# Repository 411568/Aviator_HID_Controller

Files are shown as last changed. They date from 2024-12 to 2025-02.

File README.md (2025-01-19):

<p align="center">Aviator_HID_Controller</p>

<h2>🧐 Features</h2>

The goal of this project was to design a HID controller for interfacing a number of buttons and encoders with the X-Plane flight simulator software.

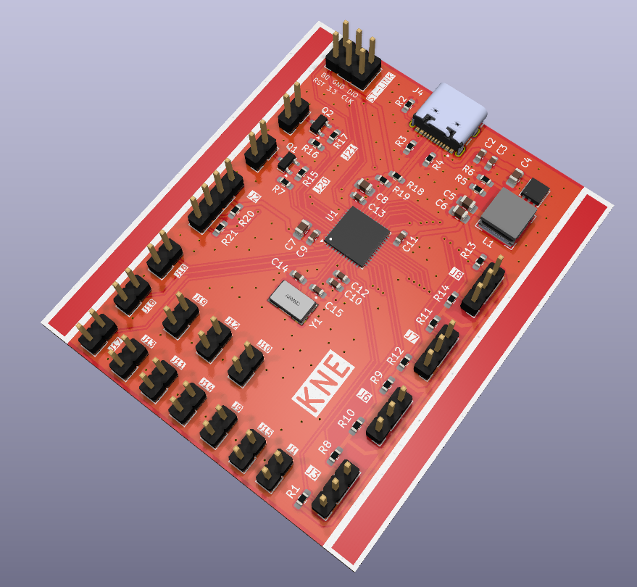
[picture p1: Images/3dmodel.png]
PCB 3d model


Here're some of the project's best features:

*  11 x button input
*  4 x rotary encoder input
*  1 x I2C interface connector
*  2 x 5V power output
*  USB type C for communication and power
*  HID keyboard interface

<h2>💻 Built with</h2>

Technologies used in the project:

*  STM32F072 microcontroller
*  ST1S06 buck converter
*  USB type C - HID communication
*  2-layer 0.8 mm FR4 PCB

<h2>🛡️ License:</h2>

This project is licensed under the MIT License.

<h2> 🙋‍♂️Authors </h2>

- Krzysztof Sikora

<h2>💖Like my work?</h2>

If you have any questions about the project feel free to contact us via email: krzysieksikora717@gmail.com

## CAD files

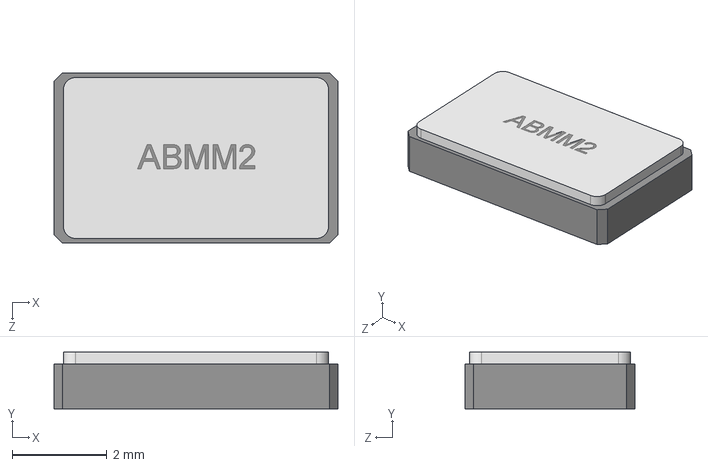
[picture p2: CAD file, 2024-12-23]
Aviator_Controller/components/ABMM2-32.000MHZ-E2F-T--3DModel-STEP-400430.STEP
6.00 x 1.20 x 3.60 mm

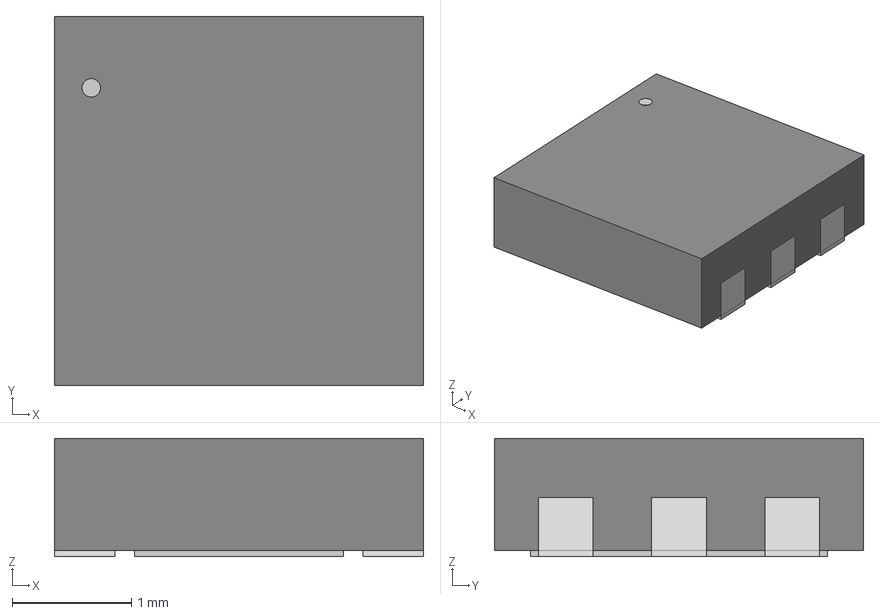
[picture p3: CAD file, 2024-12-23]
Aviator_Controller/components/ST1S06PU33R/DFN_6PU33R_STM.step
3.10 x 3.10 x 0.993 mm

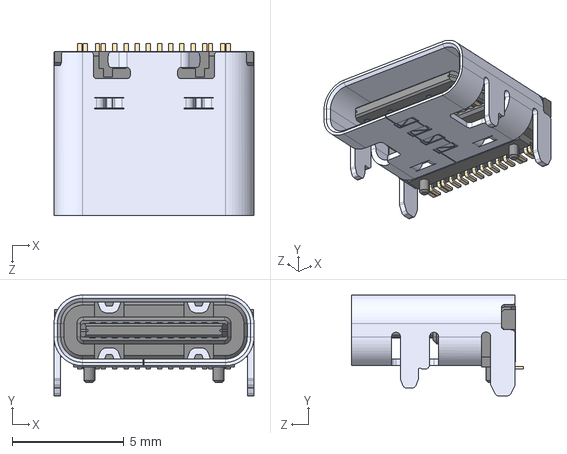
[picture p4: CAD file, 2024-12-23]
Aviator_Controller/components/USB4105GFA120/USB4105GFA120.step
8.94 x 4.51 x 7.71 mm

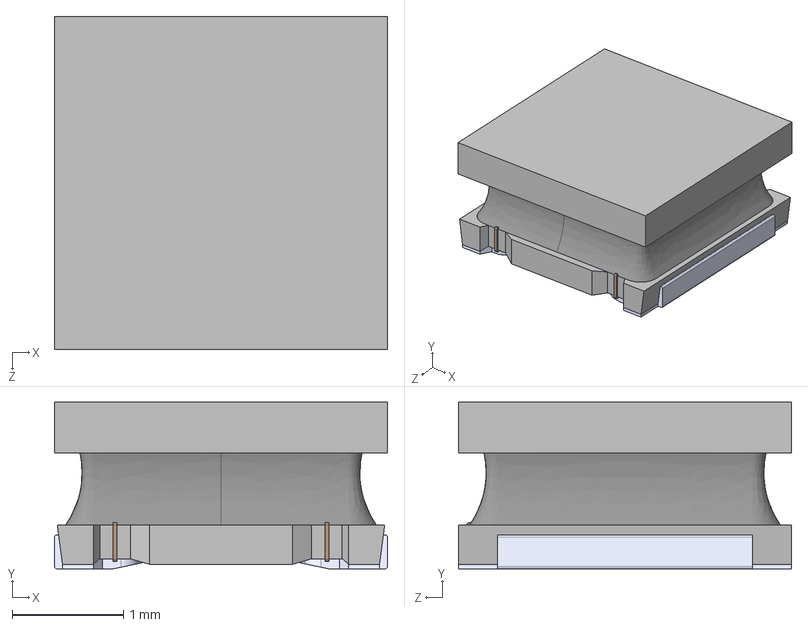
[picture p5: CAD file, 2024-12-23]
Aviator_Controller/components/LQH3NPN100MMEK.STEP
3.00 x 1.50 x 3.00 mm

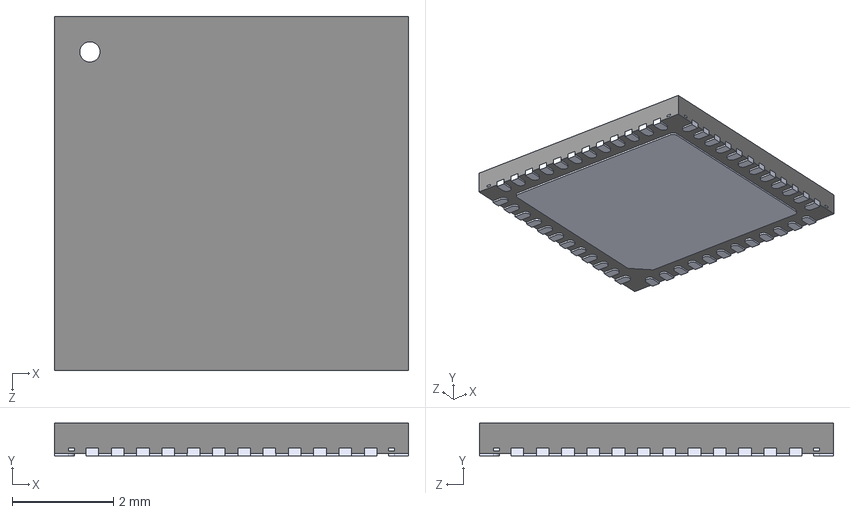
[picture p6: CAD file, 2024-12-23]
Aviator_Controller/components/STM32F072C8U6.STEP
7.00 x 0.65 x 7.00 mm

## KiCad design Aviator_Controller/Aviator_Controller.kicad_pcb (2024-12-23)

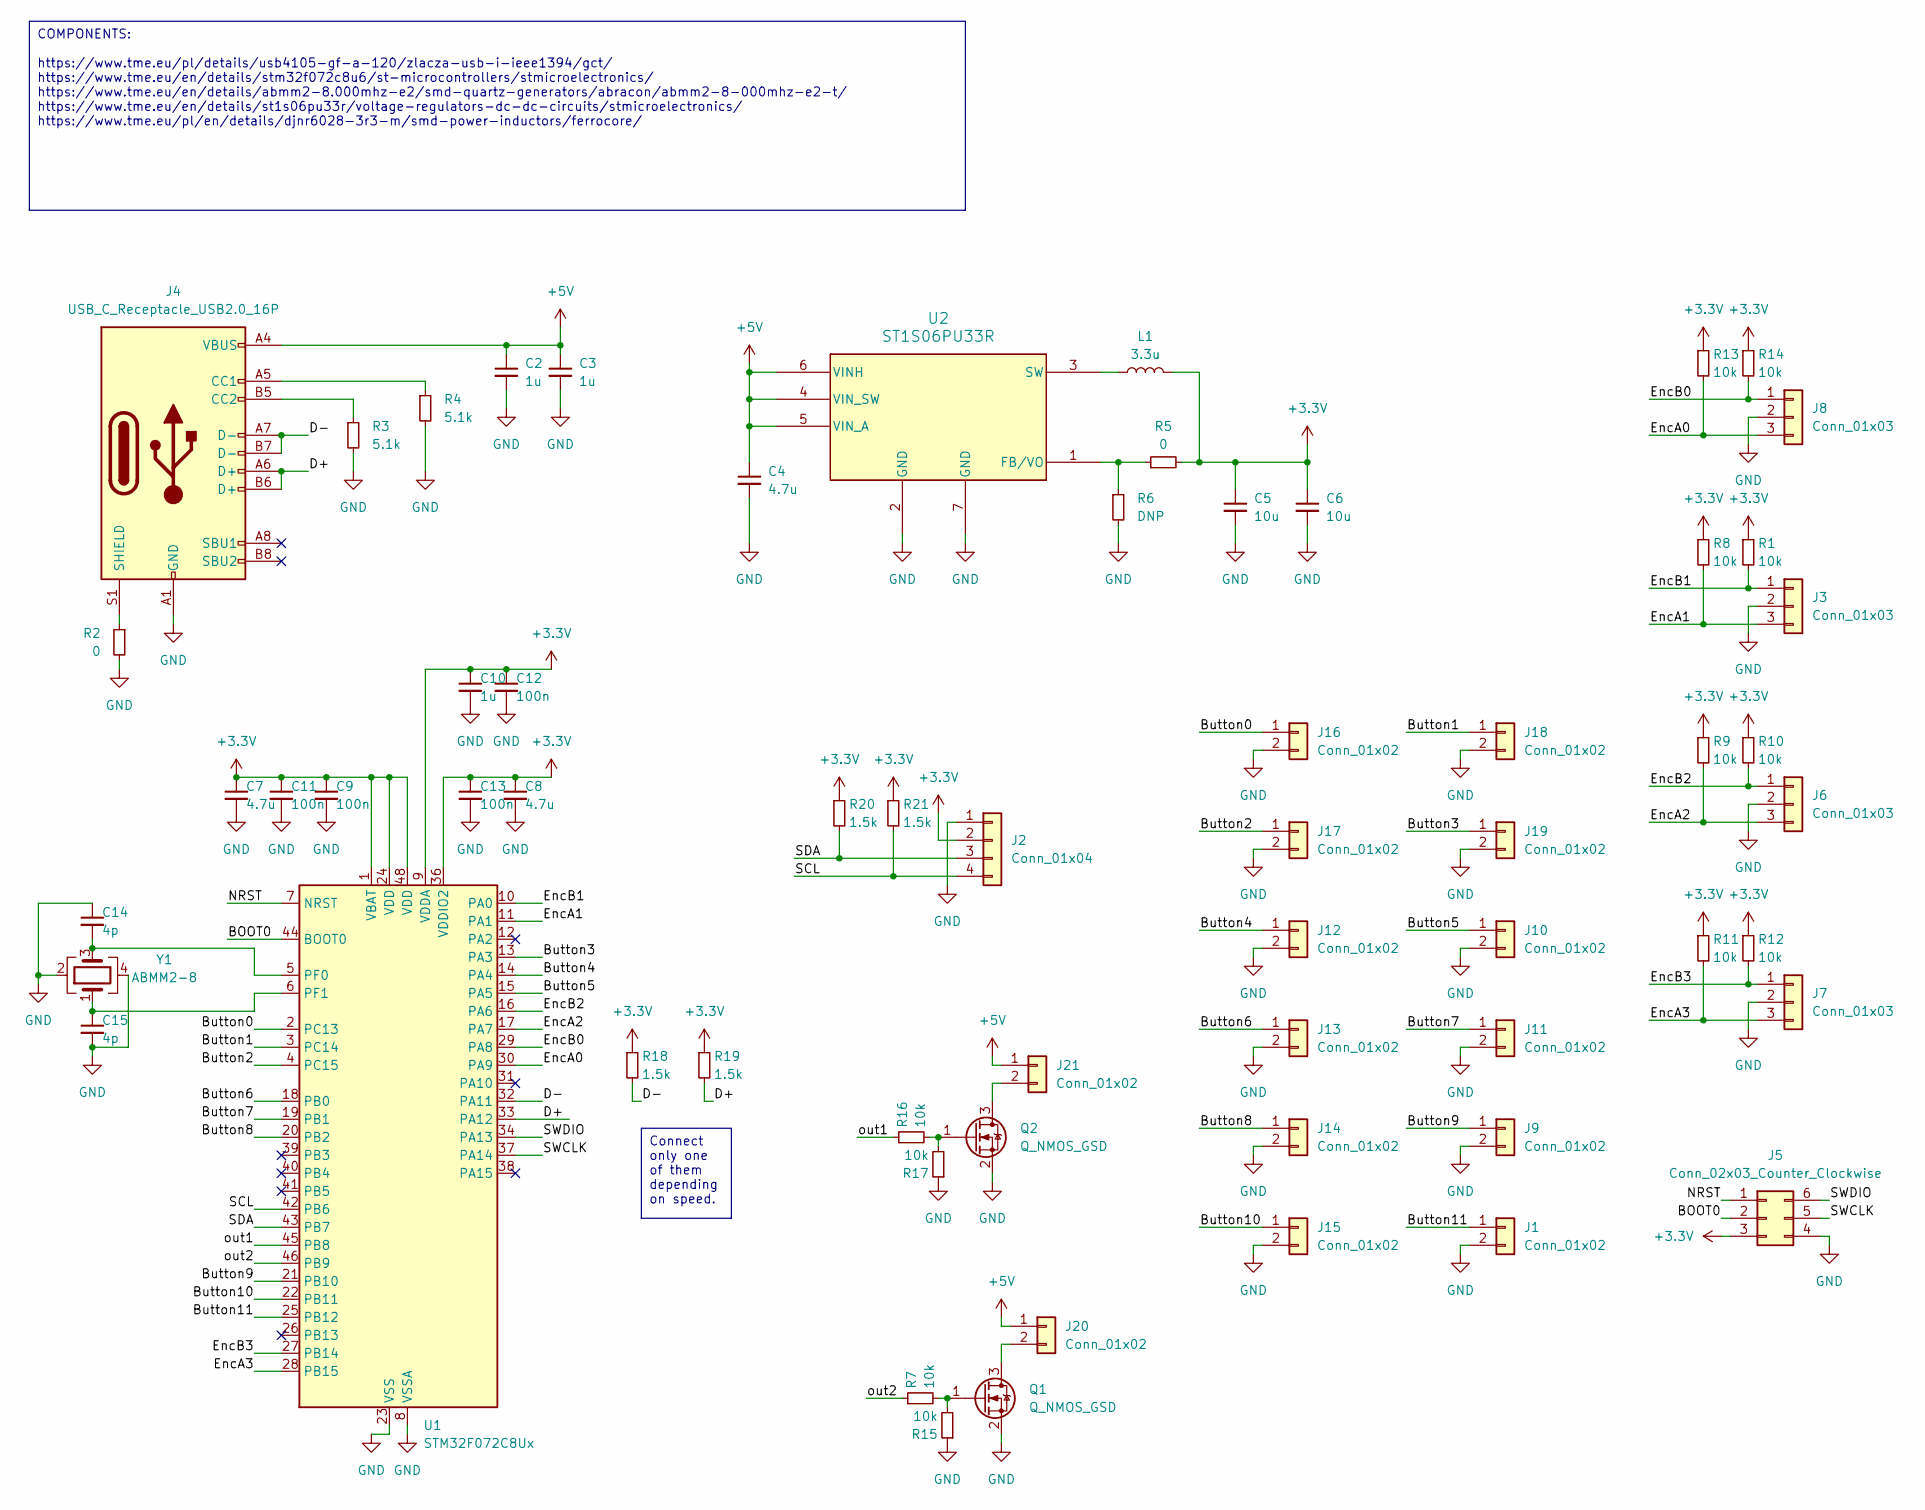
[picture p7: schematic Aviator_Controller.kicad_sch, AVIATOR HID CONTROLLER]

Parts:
C2, C3, C10: 1u; C_0603_1608Metric_Pad1.08x0.95mm_HandSolder
C4, C7, C8: 4.7u; C_0805_2012Metric_Pad1.18x1.45mm_HandSolder
C5, C6: 10u; C_0805_2012Metric_Pad1.18x1.45mm_HandSolder
C9, C11, C12, C13: 100n; C_0603_1608Metric_Pad1.08x0.95mm_HandSolder
C14, C15: 4p; C_0603_1608Metric_Pad1.08x0.95mm_HandSolder
J1, J9, J10, J11, J12, J13, J14, J15, J16, J17, J18, J19, J20, J21: Conn_01x02; PinHeader_1x02_P2.54mm_Vertical
J2: Conn_01x04; PinHeader_1x04_P2.54mm_Vertical
J3, J6, J7, J8: Conn_01x03; PinHeader_1x03_P2.54mm_Vertical
J4: USB_C_Receptacle_USB2.0_16P; GCT_USB4105GFA120
J5: Conn_02x03_Counter_Clockwise; PinHeader_2x03_P2.54mm_Vertical
L1: 3.3u; L_Bourns-SRN6028
Q1, Q2: Q_NMOS_GSD; SOT-23
R1, R7, R8, R9, R10, R11, R12, R13, R14, R15, R16, R17: 10k; R_0603_1608Metric_Pad0.98x0.95mm_HandSolder
R2, R5: 0; R_0603_1608Metric_Pad0.98x0.95mm_HandSolder
R3, R4: 5.1k; R_0603_1608Metric_Pad0.98x0.95mm_HandSolder
R6: DNP; R_0603_1608Metric_Pad0.98x0.95mm_HandSolder
R18, R19, R20, R21: 1.5k; R_0603_1608Metric_Pad0.98x0.95mm_HandSolder
U1: STM32F072C8Ux; QFN-48-1EP_7x7mm_P0.5mm_EP5.6x5.6mm
U2: ST1S06PU33R; DFN_6PU33R_STM
Y1: ABMM2-8; XTAL_ABMM2-8.000MHZ-E2-T

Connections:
+3.3V: C5.1, C6.1, C7.1, C8.1, C9.1, C10.1, C11.1, C12.1, C13.1, J2.2, J5.3, L1.2, R1.1, R5.2, R8.1, R9.1, R10.1, R11.1, R12.1, R13.1, R14.1, R18.1, R19.1, R20.1, R21.1, U1.1 (VBAT), U1.9 (VDDA), U1.24 (VDD), U1.36 (VDDIO2), U1.48 (VDD)
+5V: C2.1, C3.1, C4.1, J4.A4 (VBUS), J4.A9 (VBUS), J4.B4 (VBUS), J4.B9 (VBUS), J20.1, J21.1, U2.4 (VIN_SW), U2.5 (VIN_A), U2.6 (VINH)
/BOOT0: J5.2, U1.44 (BOOT0)
/Button0: J16.1, U1.2 (PC13)
/Button1: J18.1, U1.3 (PC14)
/Button2: J17.1, U1.4 (PC15)
/Button3: J19.1, U1.13 (PA3)
/Button4: J12.1, U1.14 (PA4)
/Button5: J10.1, U1.15 (PA5)
/Button6: J13.1, U1.18 (PB0)
/Button7: J11.1, U1.19 (PB1)
/Button8: J14.1, U1.20 (PB2)
/Button9: J9.1, U1.21 (PB10)
/Button10: J15.1, U1.22 (PB11)
/Button11: J1.1, U1.25 (PB12)
/D+: J4.A6 (D+), J4.B6 (D+), R19.2, U1.33 (PA12)
/D-: J4.A7 (D-), J4.B7 (D-), R18.2, U1.32 (PA11)
/EncA0: J8.3, R13.2, U1.30 (PA9)
/EncA1: J3.3, R8.2, U1.11 (PA1)
/EncA2: J6.3, R9.2, U1.17 (PA7)
/EncA3: J7.3, R11.2, U1.28 (PB15)
/EncB0: J8.1, R14.2, U1.29 (PA8)
/EncB1: J3.1, R1.2, U1.10 (PA0)
/EncB2: J6.1, R10.2, U1.16 (PA6)
/EncB3: J7.1, R12.2, U1.27 (PB14)
/NRST: J5.1, U1.7 (NRST)
/SCL: J2.4, R21.2, U1.42 (PB6)
/SDA: J2.3, R20.2, U1.43 (PB7)
/SWCLK: J5.5, U1.37 (PA14)
/SWDIO: J5.6, U1.34 (PA13)
/out1: R16.1, U1.45 (PB8)
/out2: R7.1, U1.46 (PB9)
GND: C2.2, C3.2, C4.2, C5.2, C6.2, C7.2, C8.2, C9.2, C10.2, C11.2, C12.2, C13.2, C14.1, C15.2, J1.2, J2.1, J3.2, J4.A1 (GND), J4.A12 (GND), J4.B1 (GND), J4.B12 (GND), J5.4, J6.2, J7.2, J8.2, J9.2, J10.2, J11.2, J12.2, J13.2, J14.2, J15.2, J16.2, J17.2, J18.2, J19.2, Q1.2 (S), Q2.2 (S), R2.2, R3.2, R4.2, R6.2, R15.1, R17.1, U1.8 (VSSA), U1.23 (VSS), U1.35 (VSS), U1.47 (VSS), U1.49 (VSS), U2.2 (GND), U2.7 (GND), Y1.2, Y1.4
unnamed: J4.A5 (CC1), R4.1
unnamed: J4.B5 (CC2), R3.1
unnamed: J4.S1 (SHIELD), R2.1
unnamed: J20.2, Q1.3 (D)
unnamed: J21.2, Q2.3 (D)
unnamed: Q1.1 (G), R7.2, R15.2
unnamed: Q2.1 (G), R16.2, R17.2
unnamed: C14.2, U1.5 (PF0), Y1.3
unnamed: C15.1, U1.6 (PF1), Y1.1
unnamed: R5.1, R6.1, U2.1 (FB/VO)
unnamed: L1.1, U2.3 (SW)

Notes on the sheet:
Connect only one of them depending on speed.
COMPONENTS: https://www.tme.eu/pl/details/usb4105-gf-a-120/zlacza-usb-i-ieee1394/gct/ https://www.tme.eu/en/details/stm32f072c8u6/st-microcontrollers/stmicroelectronics/ https://www.tme.eu/en/details/abmm2-8.000mhz-e2/smd-quartz-generators/abracon/abmm2-8-000mhz-e2-t/ https://www.tme.eu/en/details/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

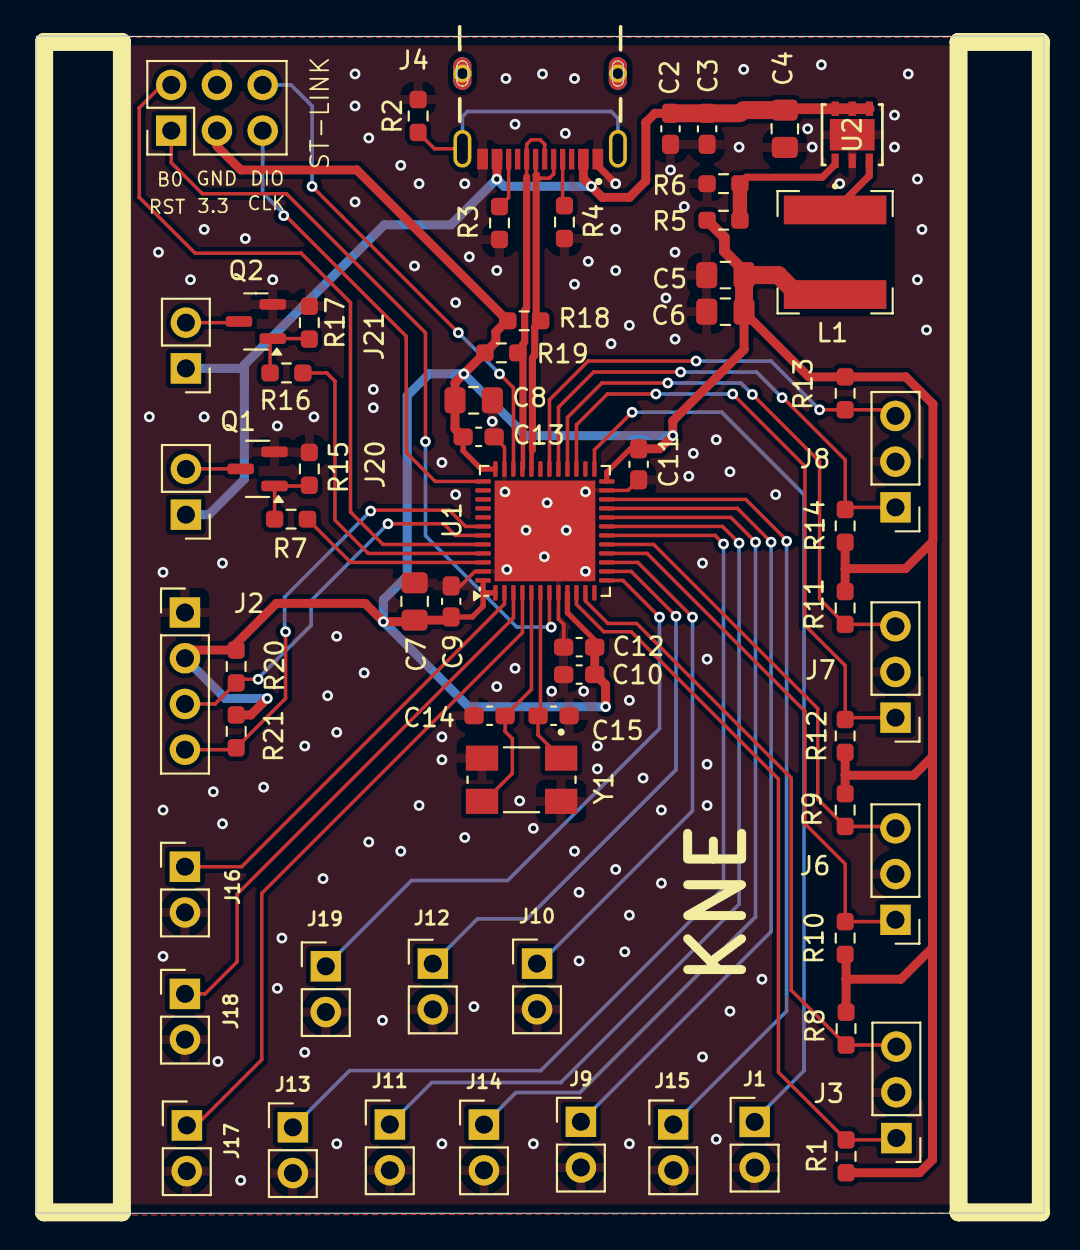
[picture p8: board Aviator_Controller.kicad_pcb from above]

Board: 2 copper layers, 56.0 x 65.4 mm, 62 parts (0 on the bottom side), 44 nets.

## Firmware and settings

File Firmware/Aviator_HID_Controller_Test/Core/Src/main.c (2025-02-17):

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
/* Includes ------------------------------------------------------------------*/
#include "main.h"
#include "usb_device.h"

/* USER CODE BEGIN Includes */
#include "usbd_hid.h"
#include "keyboard_Report_Descriptor.h"
#include <stdbool.h>
/* USER CODE END Includes */

/* USER CODE BEGIN PD */
#define DEBOUNCE_DELAY_MS 100
/* USER CODE END PD */

I2C_HandleTypeDef hi2c1;

TIM_HandleTypeDef htim1;
TIM_HandleTypeDef htim2;
TIM_HandleTypeDef htim3;

/* USER CODE BEGIN PV */
typedef enum {
    KEYCODE_A = 0x04,  // Button0
    KEYCODE_B = 0x05,  // Button1
    KEYCODE_C = 0x06,  // Button2
    KEYCODE_D = 0x07,  // Button3
    KEYCODE_E = 0x08,  // Button4
    KEYCODE_F = 0x09,  // Button5
    KEYCODE_G = 0x0A,  // Button6
    KEYCODE_H = 0x0B,  // Button7
    KEYCODE_I = 0x0C,  // Button8
    KEYCODE_J = 0x0D,  // Button9
    KEYCODE_K = 0x0E,  // Button10
    KEYCODE_L = 0x0F,  // Button11
    KEYCODE_NONE = 0x00 // No key
} KeyCode;



extern USBD_HandleTypeDef hUsbDeviceFS;

typedef struct
{
	uint8_t MODIFIER;
	uint8_t RESERVED;
	uint8_t KEYCODE1;
	uint8_t KEYCODE2;
	uint8_t KEYCODE3;
	uint8_t KEYCODE4;
	uint8_t KEYCODE5;
	uint8_t KEYCODE6;
}subKeyBoard;

subKeyBoard keyBoardHIDsub = {0,0,0,0,0,0,0,0};

typedef struct 
{
    GPIO_TypeDef* port;
    uint16_t pin;
    uint8_t keycode;
} ButtonConfig;


ButtonConfig buttonConfigs[] = 
{
    {Button0_GPIO_Port, Button0_Pin, KEYCODE_A},
    {Button1_GPIO_Port, Button1_Pin, KEYCODE_B},
    {Button2_GPIO_Port, Button2_Pin, KEYCODE_C},
    {Button3_GPIO_Port, Button3_Pin, KEYCODE_D},
    {Button4_GPIO_Port, Button4_Pin, KEYCODE_E},
    {Button5_GPIO_Port, Button5_Pin, KEYCODE_F},
    {Button6_GPIO_Port, Button6_Pin, KEYCODE_G},
    {Button7_GPIO_Port, Button7_Pin, KEYCODE_H},
    {Button8_GPIO_Port, Button8_Pin, KEYCODE_I},
    {Button9_GPIO_Port, Button9_Pin, KEYCODE_J},
    {Button10_GPIO_Port, Button10_Pin, KEYCODE_K},
    {Button11_GPIO_Port, Button11_Pin, KEYCODE_L}
};

/* USER CODE END PV */

void SystemClock_Config(void);
static void MX_GPIO_Init(void);
static void MX_I2C1_Init(void);
static void MX_TIM1_Init(void);
static void MX_TIM2_Init(void);
static void MX_TIM3_Init(void);
/**
  * @brief  The application entry point.
  * @retval int
  */
int main(void)
{

  /* MCU Configuration--------------------------------------------------------*/

  /* Reset of all peripherals, Initializes the Flash interface and the Systick. */
  HAL_Init();

  /* Configure the system clock */
  SystemClock_Config();

  /* Initialize all configured peripherals */
  MX_GPIO_Init();
  MX_I2C1_Init();
  MX_TIM1_Init();
  MX_TIM2_Init();
  MX_TIM3_Init();
  MX_USB_DEVICE_Init();
  /* USER CODE BEGIN 2 */

  // Start all timers
  HAL_TIM_Encoder_Start(&htim1, TIM_CHANNEL_ALL);
  HAL_TIM_Encoder_Start(&htim2, TIM_CHANNEL_ALL);
  HAL_TIM_Encoder_Start(&htim3, TIM_CHANNEL_ALL);

  // Store the values of timer counters
  uint32_t Enc0 = TIM1->CNT;
  uint32_t Enc1 = TIM2->CNT;
  uint32_t Enc2 = TIM3->CNT;

  /* USER CODE END 2 */

  /* Infinite loop */
  /* USER CODE BEGIN WHILE */

  volatile uint16_t debounceDelay = DEBOUNCE_DELAY_MS; // Debounce delay in ms

  while (1)
  {
    // Read encoder values and send corresponding key press
    if(TIM1->CNT > Enc0)
    {
        Enc0 = TIM1->CNT;
        keyBoardHIDsub.KEYCODE1 = 0x1E;  // Press 1 key
        USBD_HID_SendReport(&hUsbDeviceFS, &keyBoardHIDsub, sizeof(keyBoardHIDsub));
    }
    if(TIM1->CNT < Enc0)
    {
        Enc0 = TIM1->CNT;
        keyBoardHIDsub.KEYCODE1 = 0x1F;  // Press 2 key
        USBD_HID_SendReport(&hUsbDeviceFS, &keyBoardHIDsub, sizeof(keyBoardHIDsub));
    }
    if(TIM2->CNT > Enc1)
    {
        Enc1 = TIM2->CNT;
        keyBoardHIDsub.KEYCODE1 = 0x20;  // Press 3 key
        USBD_HID_SendReport(&hUsbDeviceFS, &keyBoardHIDsub, sizeof(keyBoardHIDsub));
    }
    if(TIM2->CNT < Enc1)
    {
        Enc1 = TIM2->CNT;
        keyBoardHIDsub.KEYCODE1 = 0x21;  // Press 4 key
        USBD_HID_SendReport(&hUsbDeviceFS, &keyBoardHIDsub, sizeof(keyBoardHIDsub));
    }
    if(TIM3->CNT > Enc2)
    {
        Enc2 = TIM3->CNT;
        keyBoardHIDsub.KEYCODE1 = 0x22;  // Press 5 key
        USBD_HID_SendReport(&hUsbDeviceFS, &keyBoardHIDsub, sizeof(keyBoardHIDsub));
    }
    if(TIM3->CNT < Enc2)
    {
        Enc2 = TIM3->CNT;
        keyBoardHIDsub.KEYCODE1 = 0x23;  // Press 6 key
        USBD_HID_SendReport(&hUsbDeviceFS, &keyBoardHIDsub, sizeof(keyBoardHIDsub));
    }

    // Buttons

    checkAndDebounceButtonPresses();

    HAL_Delay(50); // Main loop delay
  }
    /* USER CODE END WHILE */

}

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
/* USER CODE BEGIN 4 */
void checkAndDebounceButtonPresses()
{
    for (int i = 0; i < sizeof(buttonConfigs) / sizeof(buttonConfigs[0]); i++)
    {
        if (HAL_GPIO_ReadPin(buttonConfigs[i].port, buttonConfigs[i].pin) == GPIO_PIN_RESET)
        {
            HAL_Delay(DEBOUNCE_DELAY_MS); // Debounce delay
            if (HAL_GPIO_ReadPin(buttonConfigs[i].port, buttonConfigs[i].pin) == GPIO_PIN_RESET)
            {
                keyBoardHIDsub.KEYCODE1 = buttonConfigs[i].keycode;

                // Send the key press
                USBD_HID_SendReport(&hUsbDeviceFS, &keyBoardHIDsub, sizeof(keyBoardHIDsub));
                HAL_Delay(50);
                keyBoardHIDsub.KEYCODE1 = KEYCODE_NONE;  // Release the key
                USBD_HID_SendReport(&hUsbDeviceFS, &keyBoardHIDsub, sizeof(keyBoardHIDsub));
            }
        }
    }
}
/* USER CODE END 4 */
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


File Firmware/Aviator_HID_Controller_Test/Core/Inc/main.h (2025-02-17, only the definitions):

#define Button0_Pin GPIO_PIN_13
#define Button0_GPIO_Port GPIOC
#define Button1_Pin GPIO_PIN_14
#define Button1_GPIO_Port GPIOC
#define Button2_Pin GPIO_PIN_15
#define Button2_GPIO_Port GPIOC
#define EncB1_Pin GPIO_PIN_0
#define EncB1_GPIO_Port GPIOA
#define EncA1_Pin GPIO_PIN_1
#define EncA1_GPIO_Port GPIOA
#define Button3_Pin GPIO_PIN_3
#define Button3_GPIO_Port GPIOA
#define Button4_Pin GPIO_PIN_4
#define Button4_GPIO_Port GPIOA
#define Button5_Pin GPIO_PIN_5
#define Button5_GPIO_Port GPIOA
#define EncB2_Pin GPIO_PIN_6
#define EncB2_GPIO_Port GPIOA
#define EncA2_Pin GPIO_PIN_7
#define EncA2_GPIO_Port GPIOA
#define Button6_Pin GPIO_PIN_0
#define Button6_GPIO_Port GPIOB
#define Button7_Pin GPIO_PIN_1
#define Button7_GPIO_Port GPIOB
#define Button8_Pin GPIO_PIN_2
#define Button8_GPIO_Port GPIOB
#define Button9_Pin GPIO_PIN_10
#define Button9_GPIO_Port GPIOB
#define Button10_Pin GPIO_PIN_11
#define Button10_GPIO_Port GPIOB
#define Button11_Pin GPIO_PIN_12
#define Button11_GPIO_Port GPIOB
#define EncB0_Pin GPIO_PIN_8
#define EncB0_GPIO_Port GPIOA
#define EncA0_Pin GPIO_PIN_9
#define EncA0_GPIO_Port GPIOA
#define out1_Pin GPIO_PIN_8
#define out1_GPIO_Port GPIOB
#define out2_Pin GPIO_PIN_9
#define out2_GPIO_Port GPIOB

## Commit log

2024-12-22 created kicad project
    [Aviator_Controller.kicad_pcb, Aviator_Controller.kicad_sch]
2024-12-23 added the pcb project v0.1
    [ABMM2-32.000MHZ-E2F-T--3DModel-STEP-400430.STEP, ABMM2-8.000MHZ-E2-T.step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]
2025-02-17 Changed the button read from EXTI to polling

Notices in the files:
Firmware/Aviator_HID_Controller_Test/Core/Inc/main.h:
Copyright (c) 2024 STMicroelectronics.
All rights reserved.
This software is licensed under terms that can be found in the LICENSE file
